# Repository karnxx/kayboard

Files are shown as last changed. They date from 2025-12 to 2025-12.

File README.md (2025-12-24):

# split keyboard - kayboard
https://a360.co/4jg0f7l
basically a keyboard, it can split into 3, which is a left side, a right side and a middle calculator side. so these keyboards can also join together to make 1 big keyboard via rails. 











## hardware
- uses 3  XIAO-nRF52840-SMD, one for each keyboard part. and also uses cherry mx switches.
- https://docs.google.com/spreadsheets/d/1L9tUZh8eFOhgZV8CGI-1AN47H67KgHnQl9KeM_NllnM/edit?usp=sharing

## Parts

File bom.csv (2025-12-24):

item | qty | unit cost | total cost | link | screenshots of cart
Seeed Studio XIAO nRF52840 (SMD) | 3 | 621.6 | 1864.8 | https://www.seeedstudio.com/Seeed-Studio-XIAO-nRF52840-3PCS-p-5921.html
1N5819 THT Diode | 120 | 2.22 | 266.4 | https://robu.in/product/1n5819-1w-diode-pack-of-30/
820 kΩ Resistor | 3 | 2.23 | 6.69 | https://robu.in/product/mccfr0s2j0821a20-multicomp-pro-carbon-film-resistor-820-ohm-500mw-5/?gad_source=1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
2 MΩ Resistor 1/2 W 5pcs pack | 3 | 0.8 | 5 | https://www.electroncomponents.com/2m-resistor-1_2-watt-half-cfr
cherry mx switches | 100 | 160 | 1600 | https://www.banggood.in/100-Pcs-LEOBOG-GrayWood-V3-Switch-Linear-Gray-3Pin-DIY-Gaming-Keyboard-MX-RGB-Hot-Swap-Switch-for-Custom-Mechanical-Keyboard-p-1982818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
 | 10 | 175 | 200 | https://meckeys.com/shop/accessories/keyboard-accessories/key-switches/gateron-g-pro-3-0-switch/
M3 × 4 mm Brass Heat-set Inserts (25 pcs) | 30 | 2.2 | 66 | https://onlyscrews.in/products/m4-x-4mm-brass-threaded-inserts?_pos=3&_sid=18bf98207&_ss=r
M3 × 30 mm SS Screws | 30 | 12.27 | 368 | https://onlyscrews.in/products/m3-x-30mm-phillips-csk-ss-304-screw-dia-3mm-length-30mm
keycaps | 108 | 11.03 | 1600 | https://www.banggood.in/Yogurt-145-Keys-Keycap-Set-Cherry-Profile-PBT-Sublimation-Suitable-for-61-or-68-or-75-or-84-or-87-or-89-or-96-or-98-or-100-or-104-or-1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
battery | 3 | 95 | 285 | https://www.rytronics.in/product/3-7v-300mah-602030-model-lipo-rechargeable-battery/
regulator 3.3v | 3 | 45 | 135 | https://in.element14.com/microchip/mcp1700-1202e-to/ic-ldo-250ma-1-2v-to-92-3/dp/1863922
capacitor 470 | 3 | 4.39 | 13.17 | https://sharvielectronics.com/product/470uf-6-3v-electrolytic-capacitor-85c-6x11mm-samwha/
capacitor 1 | 6 | 28.4 | 170.4
pcb | 1 | 3680 | 5760 (w/shipping)
 |  |  |  | https://evelta.com/1uf-10-50v-x7r-5-5mm-disc-ceramic-capacitor/?utm_source=chatgpt.com
pcb:

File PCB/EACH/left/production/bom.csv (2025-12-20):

Designator | Footprint | Quantity | Value | LCSC Part #
A1, ALT1, B1, C1, CAPS1, CTRL1, D16, E1, ESC1, F1, G1, K1, K2, K3, K4, K5, K6, NN1, NN2, NN3, NN4, NN5, NN6, Q1, R1, S1, SHIFT1, SPACE1, TABS1, TT1, V1, W1, WIN1, X1, X2, X3, Y1, Z1, `1 | SW_Cherry_MX_1.00u_PCB | 39 | SW_Push
BT1 | BatteryHolder_Keystone_1057_1x2032 | 1 | Battery
D1, D10, D11, D12, D13, D14, D15, D17, D18, D19, D2, D20, D21, D22, D23, D24, D25, D26, D27, D28, D29, D3, D30, D31, D32, D33, D34, D35, D36, D37, D38, D39, D4, D40, D5, D6, D7, D8, D9 | D_DO-41_SOD81_P7.62mm_Horizontal | 39 | D
R14, R2 | 0805 | 2 | R
U1 | modified-XIAO-nRF52840-SMD | 1 | XIAO-nRF52840-SMD

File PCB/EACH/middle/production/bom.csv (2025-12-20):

Designator | Footprint | Quantity | Value | LCSC Part #
*1, +1, -2, .2, /1, CTRLT1, CTRLW1, DELETE2, END1, ENTER2, HOME1, INSTERT1, N0\1, N10, N11, N2, N3, N4, N5, N6, N7, N8, N9, NUMLOCK1, PAUSE1, PGDN1, PRTSCRN1, SCRLCK1, VOLDOWN1, VOLUP1 | SW_Cherry_MX_1.00u_PCB | 30 | SW_Push
BT3 | BatteryHolder_Keystone_1057_1x2032 | 1 | Battery
D100, D101, D102, D103, D104, D105, D106, D107, D108, D109, D80, D81, D82, D83, D84, D85, D86, D87, D88, D89, D90, D91, D92, D93, D94, D95, D96, D97, D98, D99 | D_DO-41_SOD81_P7.62mm_Horizontal | 30 | D
R5, R6 | 0805 | 2 | R
U4 | modified-XIAO-nRF52840-SMD | 1 | XIAO-nRF52840-SMD

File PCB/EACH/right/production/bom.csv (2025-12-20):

Designator | Footprint | Quantity | Value | LCSC Part #
'1, ,1, -1, .1, //1, ;1, =1, BACK1, DELETE1, DOWN1, ENTER1, F10\1, F2, F3, F4, F5, H9, I1, J1, K7, KF1, L1, LEFT1, M1, N1, NN10, NN7, NN8, NN9, O1, P1, RIGHT1, U3, UP1, X4, ZSHIFT1, [1, \1, ]1 | SW_Cherry_MX_1.00u_PCB | 39 | SW_Push
BT2 | BatteryHolder_Keystone_1057_1x2032 | 1 | Battery
D41, D42, D43, D44, D45, D46, D47, D48, D49, D50, D51, D52, D53, D54, D55, D56, D57, D58, D59, D60, D61, D62, D63, D64, D65, D66, D67, D68, D69, D70, D71, D72, D73, D74, D75, D76, D77, D78, D79 | D_DO-41_SOD81_P7.62mm_Horizontal | 39 | D
R3, R4 | 0805 | 2 | R
U2 | modified-XIAO-nRF52840-SMD | 1 | XIAO-nRF52840-SMD

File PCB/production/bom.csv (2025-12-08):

Designator | Footprint | Quantity | Value | LCSC Part #
'1, *1, +1, ,1, -1, -2, .1, .2, //1, /1, ;1, =1, A1, ALT1, B1, BACK1, C1, CAPS1, CTRL1, CTRLT1, CTRLW1, D16, DELETE1, DELETE2, DOWN1, E1, END1, ENTER1, ENTER2, ESC1, F1, F10\1, F2, F3, F4, F5, G1, H9, HOME1, I1, INSTERT1, J1, K1, K2, K3, K4, K5, K6, K7, KF1, L1, LEFT1, M1, N0\1, N1, N10, N11, N2, N3, N4, N5, N6, N7, N8, N9, NN1, NN10, NN2, NN3, NN4, NN5, NN6, NN7, NN8, NN9, NUMLOCK1, O1, P1, PAUSE1, PGDN1, PRTSCRN1, Q1, R1, RIGHT1, S1, SCRLCK1, SHIFT1, SPACE1, TABS1, TT1, U3, UP1, V1, VOLDOWN1, VOLUP1, W1, WIN1, X1, X2, X3, X4, Y1, Z1, ZSHIFT1, [1, \1, ]1, `1 | SW_Cherry_MX_1.00u_PCB | 108 | SW_Push
BT1, BT2, BT3 | BatteryHolder_Keystone_1057_1x2032 | 3 | Battery
D1, D10, D100, D101, D102, D103, D104, D105, D106, D107, D108, D109, D11, D12, D13, D14, D15, D17, D18, D19, D2, D20, D21, D22, D23, D24, D25, D26, D27, D28, D29, D3, D30, D31, D32, D33, D34, D35, D36, D37, D38, D39, D4, D40, D41, D42, D43, D44, D45, D46, D47, D48, D49, D5, D50, D51, D52, D53, D54, D55, D56, D57, D58, D59, D6, D60, D61, D62, D63, D64, D65, D66, D67, D68, D69, D7, D70, D71, D72, D73, D74, D75, D76, D77, D78, D79, D8, D80, D81, D82, D83, D84, D85, D86, D87, D88, D89, D9, D90, D91, D92, D93, D94, D95, D96, D97, D98, D99 | D_DO-41_SOD81_P7.62mm_Horizontal | 108 | D
R14, R2, R3, R4, R5, R6 | 0805 | 6 | R
U1, U2, U4 | modified-XIAO-nRF52840-SMD | 3 | XIAO-nRF52840-SMD

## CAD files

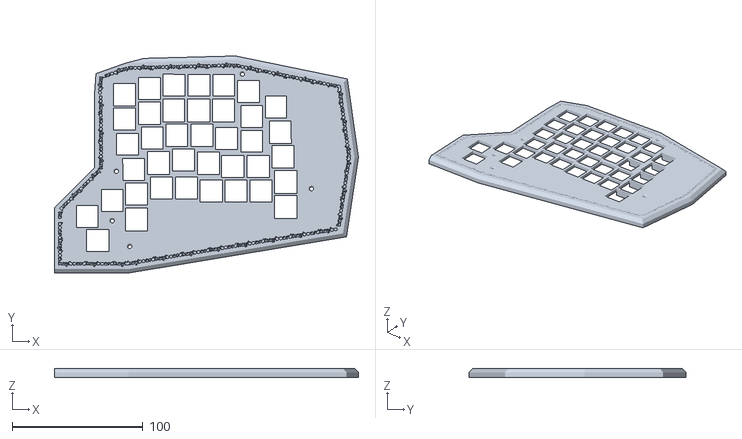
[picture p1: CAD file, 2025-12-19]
CAD/PRINTED/right_top.stl
232.8 x 166.3 x 7.10

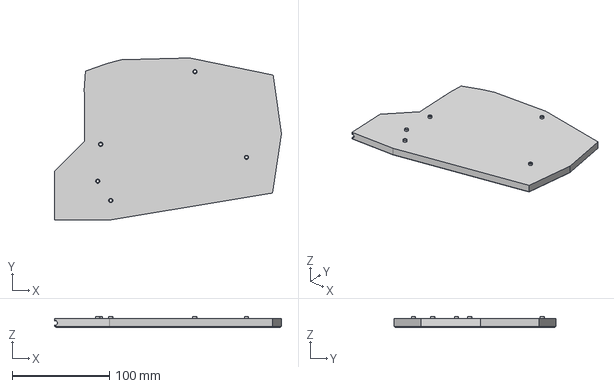
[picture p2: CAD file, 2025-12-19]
CAD/PRINTED/STEP/right_bottom.step
232.8 x 166.3 x 11.0 mm

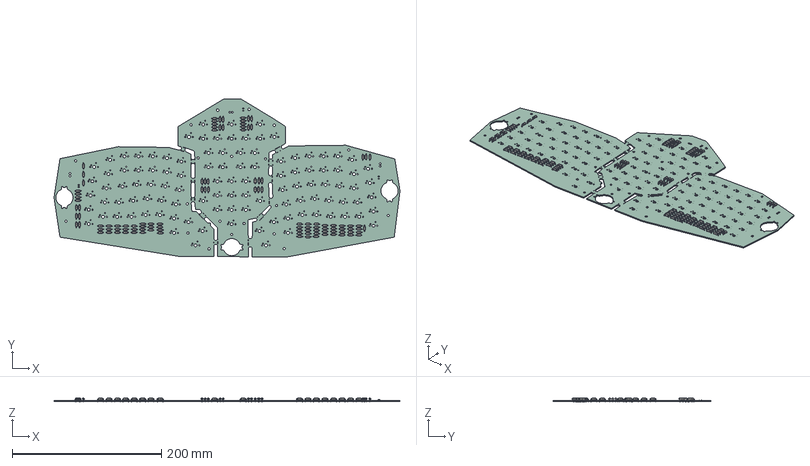
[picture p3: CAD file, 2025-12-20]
PCB/EACH/left/kayboard.step
463.0 x 211.7 x 5.71 mm
D_DO-41_SOD81_P7.62mm_Horizontal x 108
R_0805_2012Metric x 6
kayboard_PCB

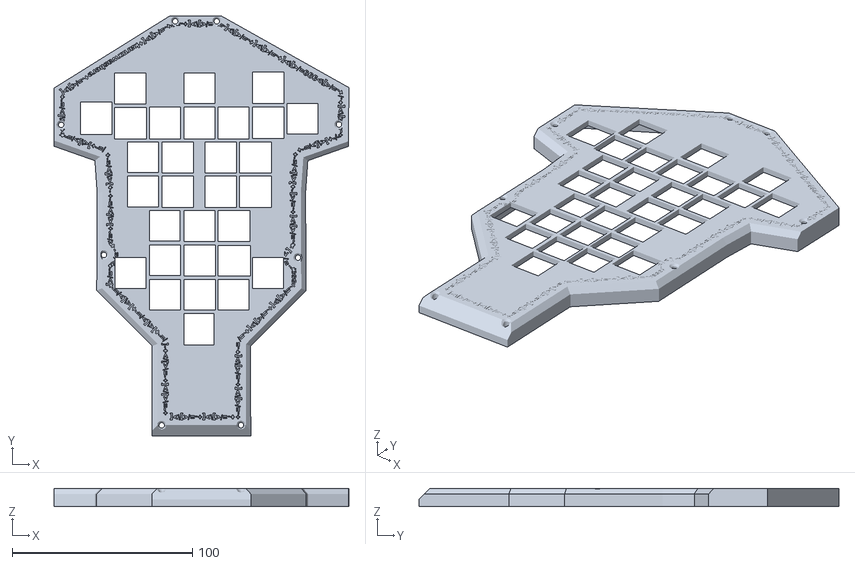
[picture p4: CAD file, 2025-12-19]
CAD/PRINTED/middle_top.stl
163.5 x 233.0 x 10.00

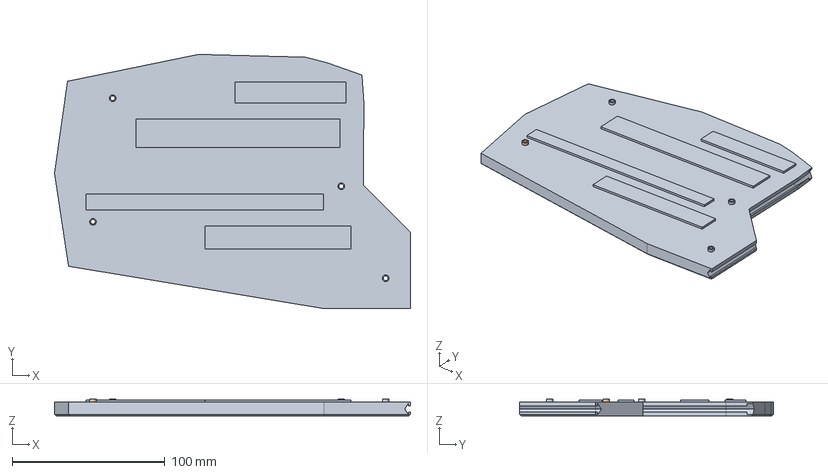
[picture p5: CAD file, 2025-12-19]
CAD/PRINTED/STEP/left_bottom.step
232.8 x 166.3 x 11.0 mm

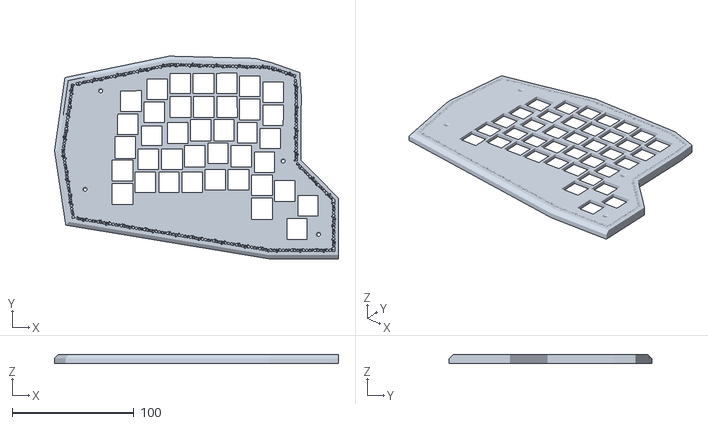
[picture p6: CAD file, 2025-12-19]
CAD/PRINTED/left_top.stl
232.8 x 166.3 x 7.00

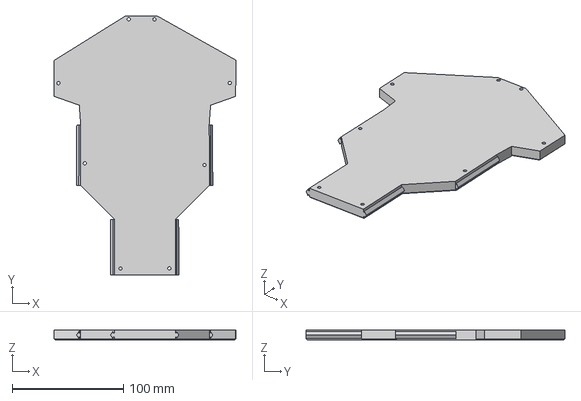
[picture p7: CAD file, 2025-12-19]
CAD/PRINTED/STEP/middle_bottom.step
163.5 x 233.0 x 9.00 mm

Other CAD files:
PCB/kayboard.step
CAD/PRINTED/left_bottom.stl
CAD/PRINTED/middle_bottom.stl
CAD/PRINTED/right_bottom.stl

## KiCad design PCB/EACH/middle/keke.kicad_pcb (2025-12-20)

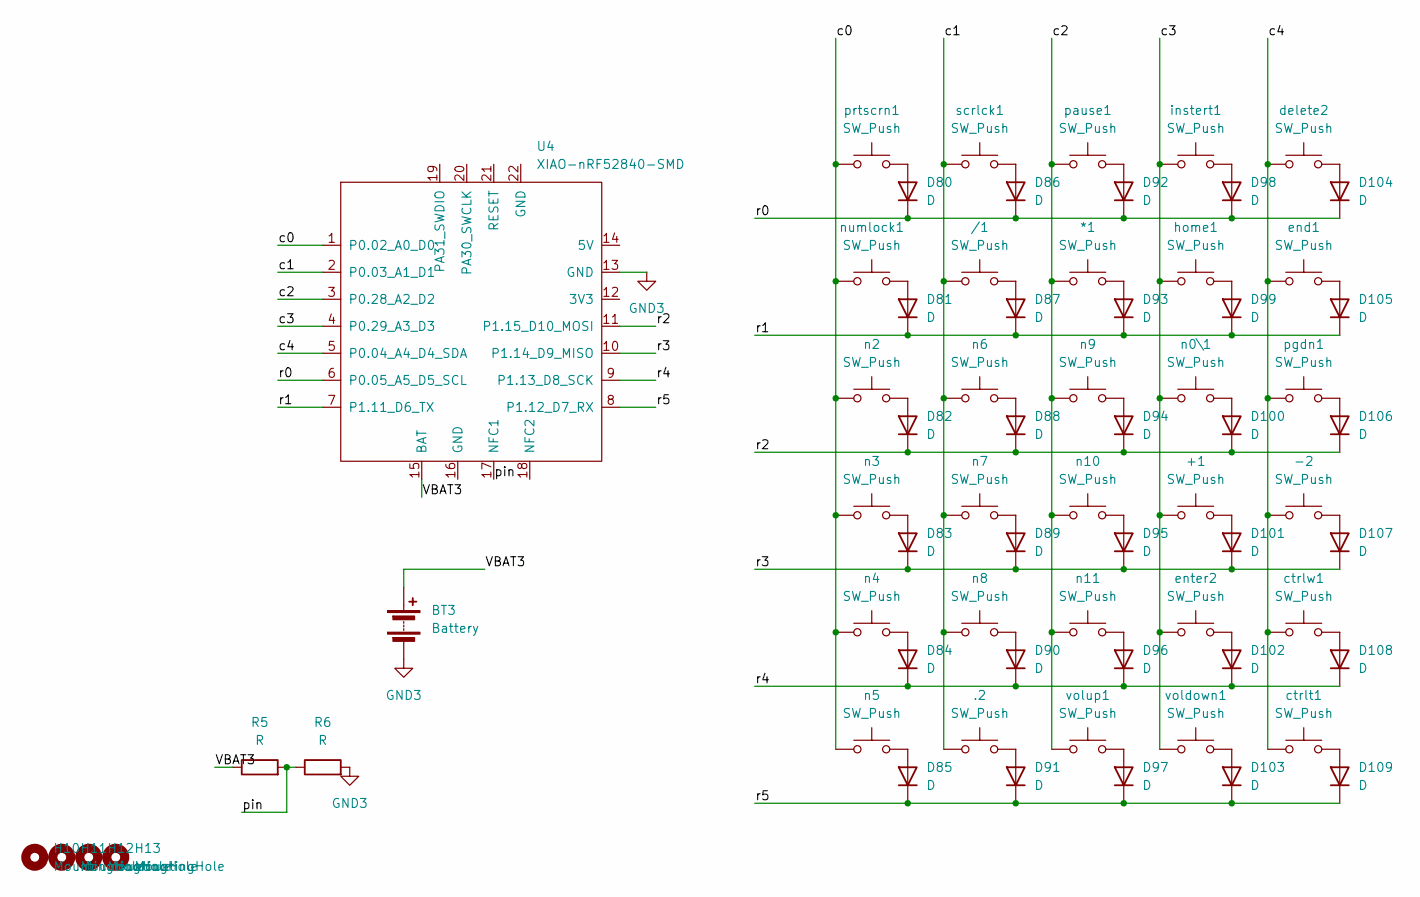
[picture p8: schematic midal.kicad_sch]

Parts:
*1: SW_Push; SW_Cherry_MX_1.00u_PCB
+1: SW_Push; SW_Cherry_MX_1.00u_PCB
-2: SW_Push; SW_Cherry_MX_1.00u_PCB
.2: SW_Push; SW_Cherry_MX_1.00u_PCB
/1: SW_Push; SW_Cherry_MX_1.00u_PCB
BT3: Battery; BatteryHolder_Keystone_1057_1x2032
D80, D81, D82, D83, D84, D85, D86, D87, D88, D89, D90, D91, D92, D93, D94, D95, D96, D97, D98, D99, D100, D101, D102, D103, D104, D105, D106, D107, D108, D109: D; D_DO-41_SOD81_P7.62mm_Horizontal
H10, H11, H12, H13: MountingHole; mouse-bite-5mm-slot
R5, R6: R; R_0805_2012Metric
U4: XIAO-nRF52840-SMD; modified-XIAO-nRF52840-SMD
ctrlt1: SW_Push; SW_Cherry_MX_1.00u_PCB
ctrlw1: SW_Push; SW_Cherry_MX_1.00u_PCB
delete2: SW_Push; SW_Cherry_MX_1.00u_PCB
end1: SW_Push; SW_Cherry_MX_1.00u_PCB
enter2: SW_Push; SW_Cherry_MX_1.00u_PCB
home1: SW_Push; SW_Cherry_MX_1.00u_PCB
instert1: SW_Push; SW_Cherry_MX_1.00u_PCB
n0\1, n2, n3, n4, n5, n6, n7, n8, n9, n10, n11: SW_Push; SW_Cherry_MX_1.00u_PCB
numlock1: SW_Push; SW_Cherry_MX_1.00u_PCB
pause1: SW_Push; SW_Cherry_MX_1.00u_PCB
pgdn1: SW_Push; SW_Cherry_MX_1.00u_PCB
prtscrn1: SW_Push; SW_Cherry_MX_1.00u_PCB
scrlck1: SW_Push; SW_Cherry_MX_1.00u_PCB
voldown1: SW_Push; SW_Cherry_MX_1.00u_PCB
volup1: SW_Push; SW_Cherry_MX_1.00u_PCB

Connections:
/middle/VBAT3: BT3.1 (+), R5.1, U4.15 (BAT)
/middle/c0: U4.1 (P0.02_A0_D0), n2.1, n3.1, n4.1, n5.1, numlock1.1, prtscrn1.1
/middle/c1: .2.1, /1.1, U4.2 (P0.03_A1_D1), n6.1, n7.1, n8.1, scrlck1.1
/middle/c2: *1.1, U4.3 (P0.28_A2_D2), n9.1, n10.1, n11.1, pause1.1, volup1.1
/middle/c3: +1.1, U4.4 (P0.29_A3_D3), enter2.1, home1.1, instert1.1, n0\1.1, voldown1.1
/middle/c4: -2.1, U4.5 (P0.04_A4_D4_SDA), ctrlt1.1, ctrlw1.1, delete2.1, end1.1, pgdn1.1
/middle/pin: R5.2, R6.1, U4.17 (NFC1)
/middle/r0: D80.1 (K), D86.1 (K), D92.1 (K), D98.1 (K), D104.1 (K), U4.6 (P0.05_A5_D5_SCL)
/middle/r1: D81.1 (K), D87.1 (K), D93.1 (K), D99.1 (K), D105.1 (K), U4.7 (P1.11_D6_TX)
/middle/r2: D82.1 (K), D88.1 (K), D94.1 (K), D100.1 (K), D106.1 (K), U4.11 (P1.15_D10_MOSI)
/middle/r3: D83.1 (K), D89.1 (K), D95.1 (K), D101.1 (K), D107.1 (K), U4.10 (P1.14_D9_MISO)
/middle/r4: D84.1 (K), D90.1 (K), D96.1 (K), D102.1 (K), D108.1 (K), U4.9 (P1.13_D8_SCK)
/middle/r5: D85.1 (K), D91.1 (K), D97.1 (K), D103.1 (K), D109.1 (K), U4.8 (P1.12_D7_RX)
GND3: BT3.2 (-), R6.2, U4.13 (GND)
unnamed: D80.2 (A), prtscrn1.2
unnamed: D81.2 (A), numlock1.2
unnamed: D82.2 (A), n2.2
unnamed: D83.2 (A), n3.2
unnamed: D84.2 (A), n4.2
unnamed: D85.2 (A), n5.2
unnamed: D86.2 (A), scrlck1.2
unnamed: /1.2, D87.2 (A)
unnamed: D88.2 (A), n6.2
unnamed: D89.2 (A), n7.2
unnamed: D90.2 (A), n8.2
unnamed: .2.2, D91.2 (A)
unnamed: D92.2 (A), pause1.2
unnamed: *1.2, D93.2 (A)
unnamed: D94.2 (A), n9.2
unnamed: D95.2 (A), n10.2
unnamed: D96.2 (A), n11.2
unnamed: D97.2 (A), volup1.2
unnamed: D98.2 (A), instert1.2
unnamed: D99.2 (A), home1.2
unnamed: D100.2 (A), n0\1.2
unnamed: +1.2, D101.2 (A)
unnamed: D102.2 (A), enter2.2
unnamed: D103.2 (A), voldown1.2
unnamed: D104.2 (A), delete2.2
unnamed: D105.2 (A), end1.2
unnamed: D106.2 (A), pgdn1.2
unnamed: -2.2, D107.2 (A)
unnamed: D108.2 (A), ctrlw1.2
unnamed: D109.2 (A), ctrlt1.2

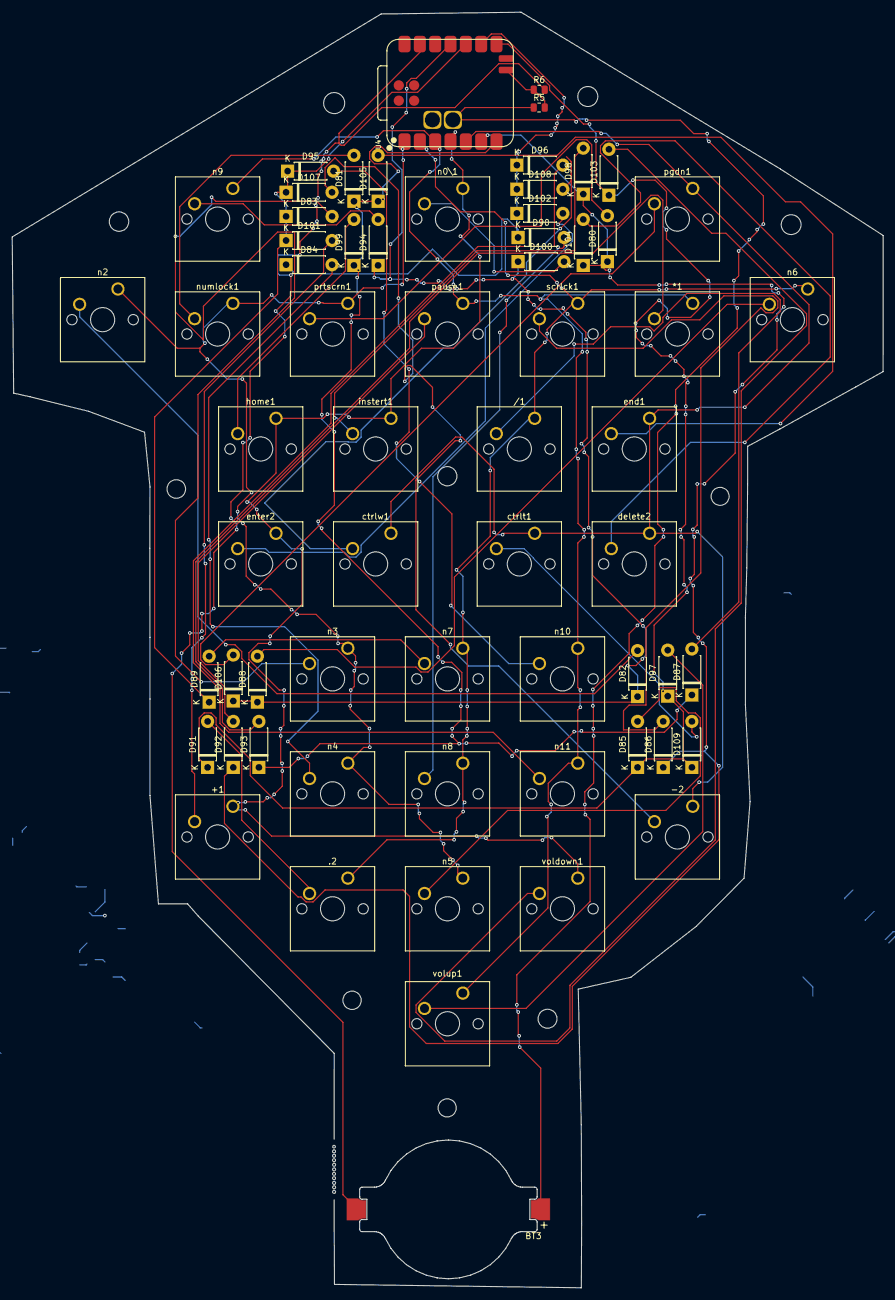
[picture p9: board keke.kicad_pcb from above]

Board: 2 copper layers, 144.3 x 211.4 mm, 64 parts (0 on the bottom side), 44 nets.

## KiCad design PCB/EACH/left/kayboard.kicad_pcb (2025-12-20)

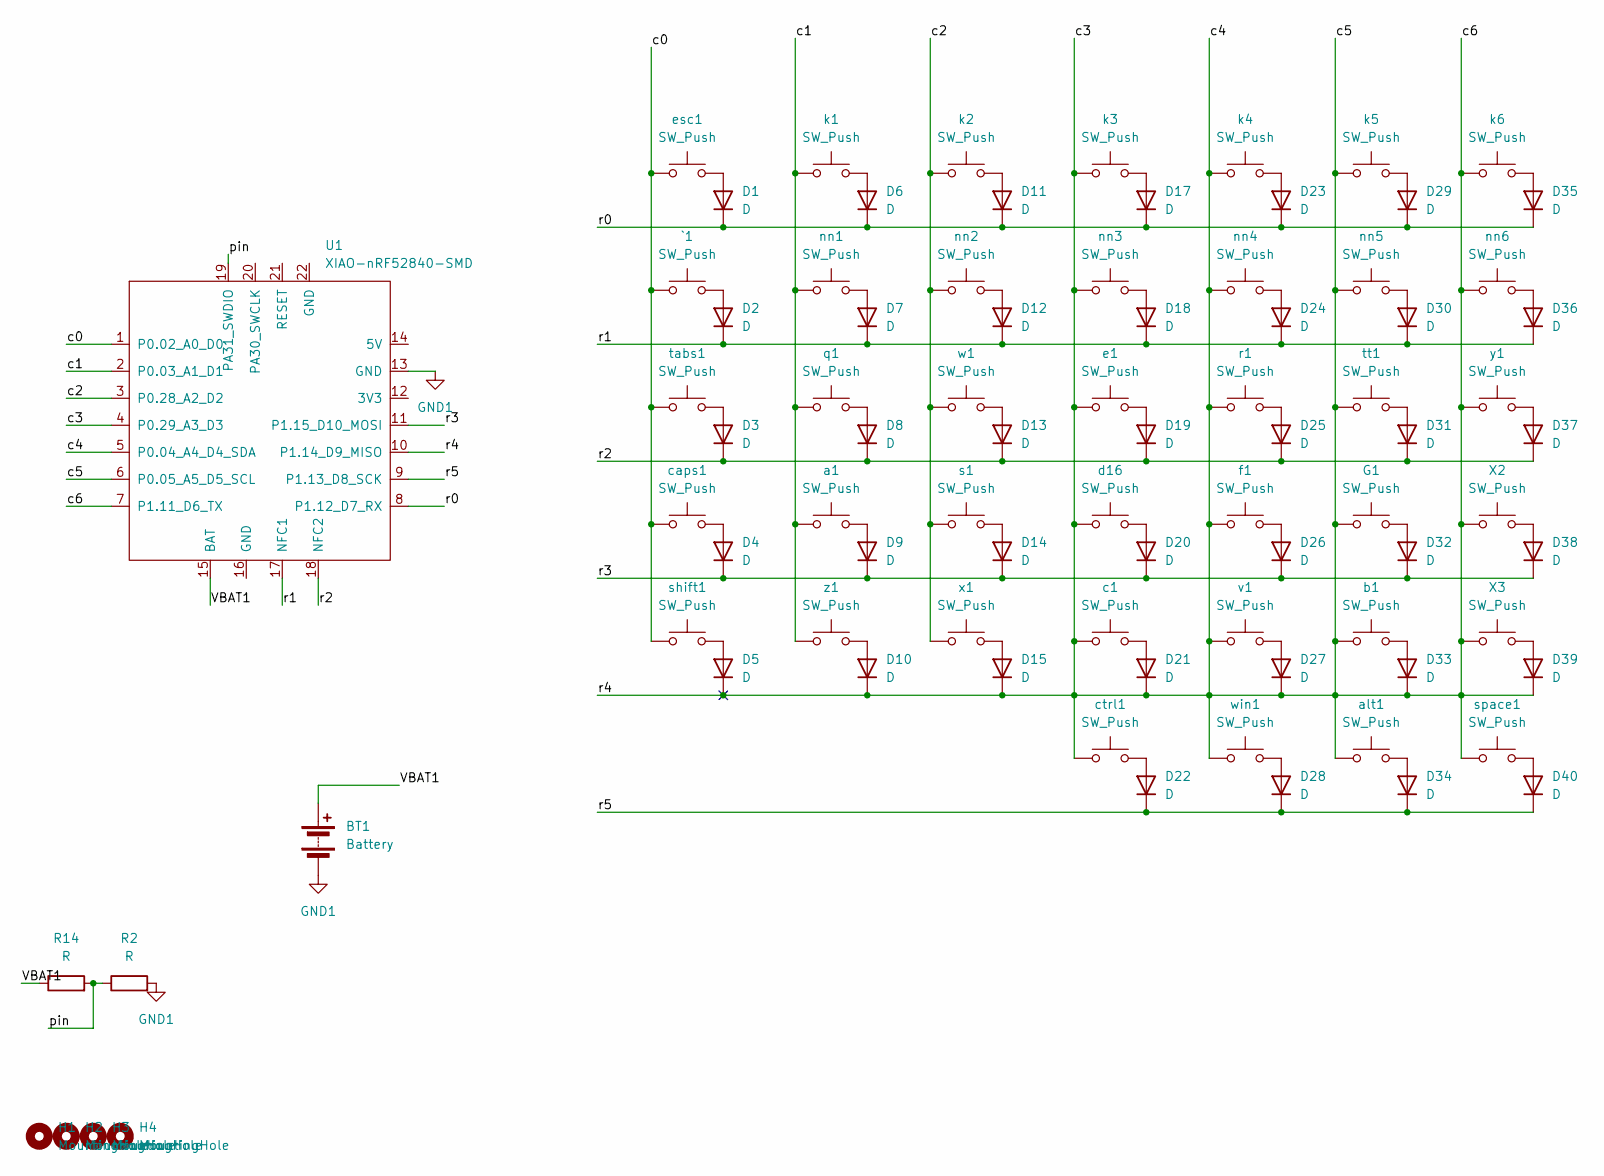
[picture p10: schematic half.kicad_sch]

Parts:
BT1: Battery; BatteryHolder_Keystone_1057_1x2032
D1, D2, D3, D4, D5, D6, D7, D8, D9, D10, D11, D12, D13, D14, D15, D17, D18, D19, D20, D21, D22, D23, D24, D25, D26, D27, D28, D29, D30, D31, D32, D33, D34, D35, D36, D37, D38, D39, D40: D; D_DO-41_SOD81_P7.62mm_Horizontal
G1: SW_Push; SW_Cherry_MX_1.00u_PCB
H1, H2, H3, H4: MountingHole; mouse-bite-5mm-slot
R2, R14: R; R_0805_2012Metric
U1: XIAO-nRF52840-SMD; modified-XIAO-nRF52840-SMD
X2, X3: SW_Push; SW_Cherry_MX_1.00u_PCB
`1: SW_Push; SW_Cherry_MX_1.00u_PCB
a1: SW_Push; SW_Cherry_MX_1.00u_PCB
alt1: SW_Push; SW_Cherry_MX_1.00u_PCB
b1: SW_Push; SW_Cherry_MX_1.00u_PCB
c1: SW_Push; SW_Cherry_MX_1.00u_PCB
caps1: SW_Push; SW_Cherry_MX_1.00u_PCB
ctrl1: SW_Push; SW_Cherry_MX_1.00u_PCB
d16: SW_Push; SW_Cherry_MX_1.00u_PCB
e1: SW_Push; SW_Cherry_MX_1.00u_PCB
esc1: SW_Push; SW_Cherry_MX_1.00u_PCB
f1: SW_Push; SW_Cherry_MX_1.00u_PCB
k1, k2, k3, k4, k5, k6: SW_Push; SW_Cherry_MX_1.00u_PCB
nn1, nn2, nn3, nn4, nn5, nn6: SW_Push; SW_Cherry_MX_1.00u_PCB
q1: SW_Push; SW_Cherry_MX_1.00u_PCB
r1: SW_Push; SW_Cherry_MX_1.00u_PCB
s1: SW_Push; SW_Cherry_MX_1.00u_PCB
shift1: SW_Push; SW_Cherry_MX_1.00u_PCB
space1: SW_Push; SW_Cherry_MX_1.00u_PCB
tabs1: SW_Push; SW_Cherry_MX_1.00u_PCB
tt1: SW_Push; SW_Cherry_MX_1.00u_PCB
v1: SW_Push; SW_Cherry_MX_1.00u_PCB
w1: SW_Push; SW_Cherry_MX_1.00u_PCB
win1: SW_Push; SW_Cherry_MX_1.00u_PCB
x1: SW_Push; SW_Cherry_MX_1.00u_PCB
y1: SW_Push; SW_Cherry_MX_1.00u_PCB
z1: SW_Push; SW_Cherry_MX_1.00u_PCB

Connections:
/left/VBAT1: BT1.1 (+), R14.1, U1.15 (BAT)
/left/c0: U1.1 (P0.02_A0_D0), `1.1, caps1.1, esc1.1, shift1.1, tabs1.1
/left/c1: U1.2 (P0.03_A1_D1), a1.1, k1.1, nn1.1, q1.1, z1.1
/left/c2: U1.3 (P0.28_A2_D2), k2.1, nn2.1, s1.1, w1.1, x1.1
/left/c3: D5.1 (K), D10.1 (K), D15.1 (K), D21.1 (K), D27.1 (K), D33.1 (K), D39.1 (K), G1.1, U1.4 (P0.29_A3_D3), U1.5 (P0.04_A4_D4_SDA), U1.6 (P0.05_A5_D5_SCL), U1.7 (P1.11_D6_TX), U1.10 (P1.14_D9_MISO), X2.1, X3.1, alt1.1, b1.1, c1.1, ctrl1.1, d16.1, e1.1, f1.1, k3.1, k4.1, k5.1, k6.1, nn3.1, nn4.1, nn5.1, nn6.1, r1.1, space1.1, tt1.1, v1.1, win1.1, y1.1
/left/pin: R2.1, R14.2, U1.19 (PA31_SWDIO)
/left/r0: D1.1 (K), D6.1 (K), D11.1 (K), D17.1 (K), D23.1 (K), D29.1 (K), D35.1 (K), U1.8 (P1.12_D7_RX)
/left/r1: D2.1 (K), D7.1 (K), D12.1 (K), D18.1 (K), D24.1 (K), D30.1 (K), D36.1 (K), U1.17 (NFC1)
/left/r2: D3.1 (K), D8.1 (K), D13.1 (K), D19.1 (K), D25.1 (K), D31.1 (K), D37.1 (K), U1.18 (NFC2)
/left/r3: D4.1 (K), D9.1 (K), D14.1 (K), D20.1 (K), D26.1 (K), D32.1 (K), D38.1 (K), U1.11 (P1.15_D10_MOSI)
/left/r5: D22.1 (K), D28.1 (K), D34.1 (K), D40.1 (K), U1.9 (P1.13_D8_SCK)
GND1: BT1.2 (-), R2.2, U1.13 (GND)
unnamed: D1.2 (A), esc1.2
unnamed: D2.2 (A), `1.2
unnamed: D3.2 (A), tabs1.2
unnamed: D4.2 (A), caps1.2
unnamed: D5.2 (A), shift1.2
unnamed: D6.2 (A), k1.2
unnamed: D7.2 (A), nn1.2
unnamed: D8.2 (A), q1.2
unnamed: D9.2 (A), a1.2
unnamed: D10.2 (A), z1.2
unnamed: D11.2 (A), k2.2
unnamed: D12.2 (A), nn2.2
unnamed: D13.2 (A), w1.2
unnamed: D14.2 (A), s1.2
unnamed: D15.2 (A), x1.2
unnamed: D17.2 (A), k3.2
unnamed: D18.2 (A), nn3.2
unnamed: D19.2 (A), e1.2
unnamed: D20.2 (A), d16.2
unnamed: D21.2 (A), c1.2
unnamed: D22.2 (A), ctrl1.2
unnamed: D23.2 (A), k4.2
unnamed: D24.2 (A), nn4.2
unnamed: D25.2 (A), r1.2
unnamed: D26.2 (A), f1.2
unnamed: D27.2 (A), v1.2
unnamed: D28.2 (A), win1.2
unnamed: D29.2 (A), k5.2
unnamed: D30.2 (A), nn5.2
unnamed: D31.2 (A), tt1.2
unnamed: D32.2 (A), G1.2
unnamed: D33.2 (A), b1.2
unnamed: D34.2 (A), alt1.2
unnamed: D35.2 (A), k6.2
unnamed: D36.2 (A), nn6.2
unnamed: D37.2 (A), y1.2
unnamed: D38.2 (A), X2.2
unnamed: D39.2 (A), X3.2
unnamed: D40.2 (A), space1.2

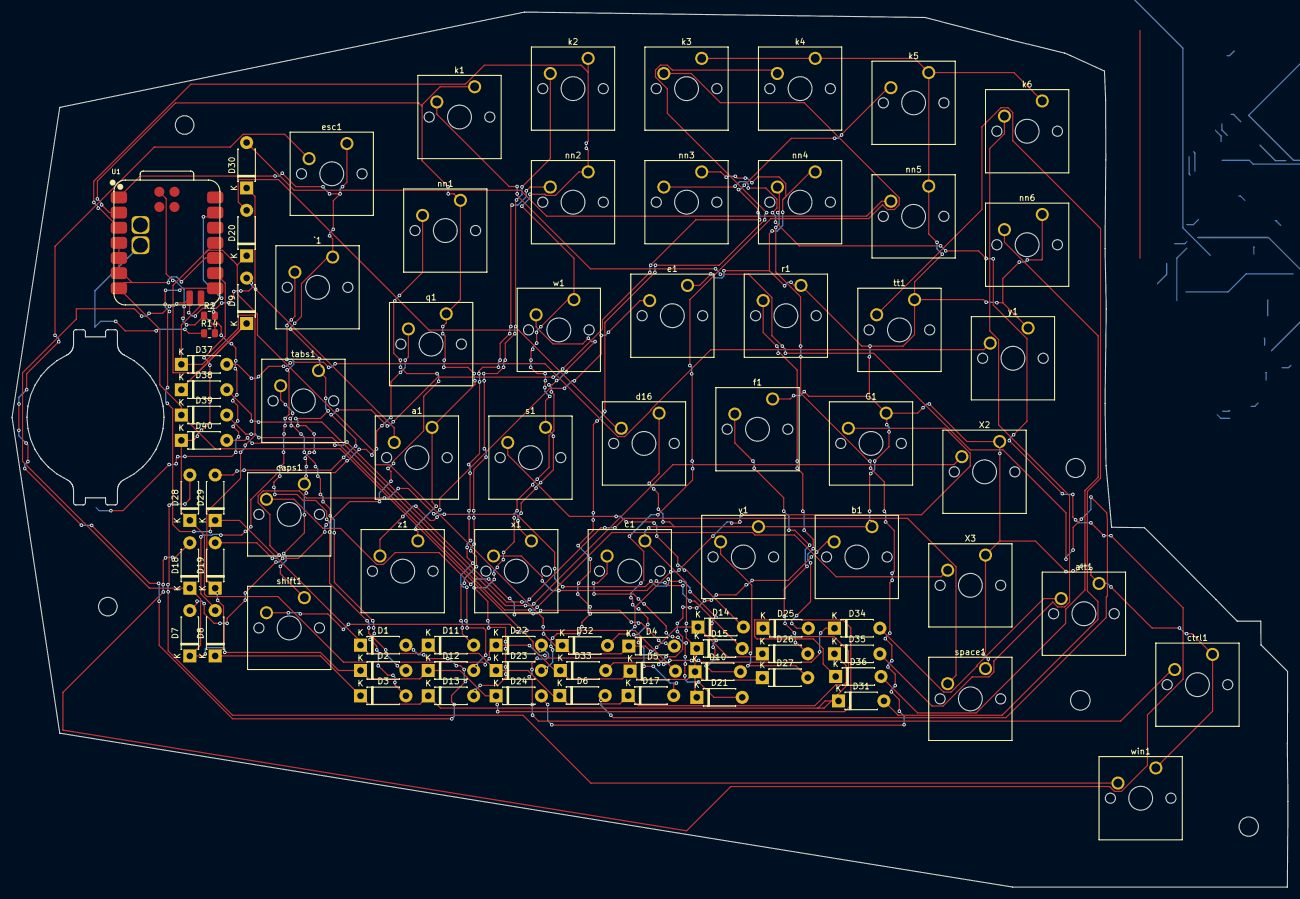
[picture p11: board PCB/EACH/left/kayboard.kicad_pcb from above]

Board: 2 copper layers, 214.1 x 146.8 mm, 82 parts (1 on the bottom side), 51 nets.

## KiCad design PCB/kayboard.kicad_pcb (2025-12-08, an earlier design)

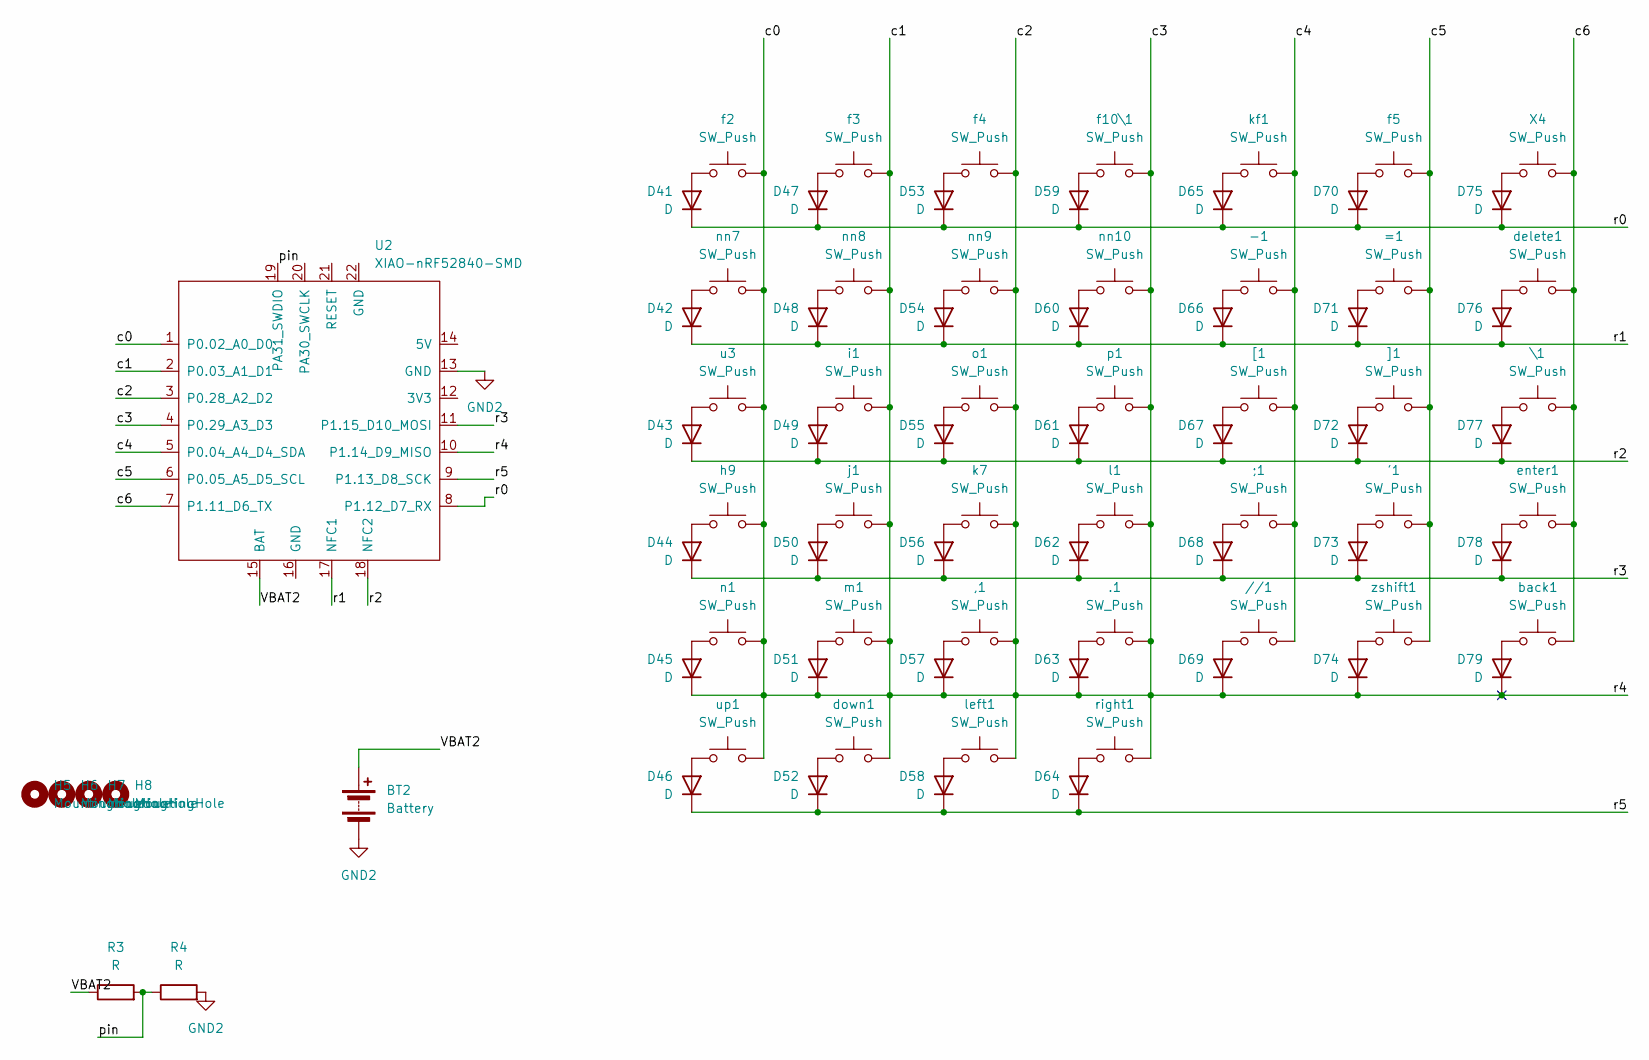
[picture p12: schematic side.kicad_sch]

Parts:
'1: SW_Push; SW_Cherry_MX_1.00u_PCB
,1: SW_Push; SW_Cherry_MX_1.00u_PCB
-1: SW_Push; SW_Cherry_MX_1.00u_PCB
.1: SW_Push; SW_Cherry_MX_1.00u_PCB
//1: SW_Push; SW_Cherry_MX_1.00u_PCB
;1: SW_Push; SW_Cherry_MX_1.00u_PCB
=1: SW_Push; SW_Cherry_MX_1.00u_PCB
BT2: Battery; BatteryHolder_Keystone_1057_1x2032
D41, D42, D43, D44, D45, D46, D47, D48, D49, D50, D51, D52, D53, D54, D55, D56, D57, D58, D59, D60, D61, D62, D63, D64, D65, D66, D67, D68, D69, D70, D71, D72, D73, D74, D75, D76, D77, D78, D79: D; D_DO-41_SOD81_P7.62mm_Horizontal
H5, H6, H7, H8: MountingHole; mouse-bite-5mm-slot
R3, R4: R; R_0805_2012Metric
U2: XIAO-nRF52840-SMD; modified-XIAO-nRF52840-SMD
X4: SW_Push; SW_Cherry_MX_1.00u_PCB
[1: SW_Push; SW_Cherry_MX_1.00u_PCB
\1: SW_Push; SW_Cherry_MX_1.00u_PCB
]1: SW_Push; SW_Cherry_MX_1.00u_PCB
back1: SW_Push; SW_Cherry_MX_1.00u_PCB
delete1: SW_Push; SW_Cherry_MX_1.00u_PCB
down1: SW_Push; SW_Cherry_MX_1.00u_PCB
enter1: SW_Push; SW_Cherry_MX_1.00u_PCB
f2, f3, f4, f5, f10\1: SW_Push; SW_Cherry_MX_1.00u_PCB
h9: SW_Push; SW_Cherry_MX_1.00u_PCB
i1: SW_Push; SW_Cherry_MX_1.00u_PCB
j1: SW_Push; SW_Cherry_MX_1.00u_PCB
k7: SW_Push; SW_Cherry_MX_1.00u_PCB
kf1: SW_Push; SW_Cherry_MX_1.00u_PCB
l1: SW_Push; SW_Cherry_MX_1.00u_PCB
left1: SW_Push; SW_Cherry_MX_1.00u_PCB
m1: SW_Push; SW_Cherry_MX_1.00u_PCB
n1: SW_Push; SW_Cherry_MX_1.00u_PCB
nn7, nn8, nn9, nn10: SW_Push; SW_Cherry_MX_1.00u_PCB
o1: SW_Push; SW_Cherry_MX_1.00u_PCB
p1: SW_Push; SW_Cherry_MX_1.00u_PCB
right1: SW_Push; SW_Cherry_MX_1.00u_PCB
u3: SW_Push; SW_Cherry_MX_1.00u_PCB
up1: SW_Push; SW_Cherry_MX_1.00u_PCB
zshift1: SW_Push; SW_Cherry_MX_1.00u_PCB

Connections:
/right/VBAT2: BT2.1 (+), R3.1, U2.15 (BAT)
/right/c0: ,1.1, .1.1, D45.1 (K), D51.1 (K), D57.1 (K), D63.1 (K), D69.1 (K), D74.1 (K), D79.1 (K), U2.1 (P0.02_A0_D0), U2.2 (P0.03_A1_D1), U2.3 (P0.28_A2_D2), U2.4 (P0.29_A3_D3), U2.10 (P1.14_D9_MISO), down1.1, f2.1, f3.1, f4.1, f10\1.1, h9.1, i1.1, j1.1, k7.1, l1.1, left1.1, m1.1, n1.1, nn7.1, nn8.1, nn9.1, nn10.1, o1.1, p1.1, right1.1, u3.1, up1.1
/right/c4: -1.1, //1.1, ;1.1, U2.5 (P0.04_A4_D4_SDA), [1.1, kf1.1
/right/c5: '1.1, =1.1, U2.6 (P0.05_A5_D5_SCL), ]1.1, f5.1, zshift1.1
/right/c6: U2.7 (P1.11_D6_TX), X4.1, \1.1, back1.1, delete1.1, enter1.1
/right/pin: R3.2, R4.1, U2.19 (PA31_SWDIO)
/right/r0: D41.1 (K), D47.1 (K), D53.1 (K), D59.1 (K), D65.1 (K), D70.1 (K), D75.1 (K), U2.8 (P1.12_D7_RX)
/right/r1: D42.1 (K), D48.1 (K), D54.1 (K), D60.1 (K), D66.1 (K), D71.1 (K), D76.1 (K), U2.17 (NFC1)
/right/r2: D43.1 (K), D49.1 (K), D55.1 (K), D61.1 (K), D67.1 (K), D72.1 (K), D77.1 (K), U2.18 (NFC2)
/right/r3: D44.1 (K), D50.1 (K), D56.1 (K), D62.1 (K), D68.1 (K), D73.1 (K), D78.1 (K), U2.11 (P1.15_D10_MOSI)
/right/r5: D46.1 (K), D52.1 (K), D58.1 (K), D64.1 (K), U2.9 (P1.13_D8_SCK)
GND2: BT2.2 (-), R4.2, U2.13 (GND)
unnamed: D41.2 (A), f2.2
unnamed: D42.2 (A), nn7.2
unnamed: D43.2 (A), u3.2
unnamed: D44.2 (A), h9.2
unnamed: D45.2 (A), n1.2
unnamed: D46.2 (A), up1.2
unnamed: D47.2 (A), f3.2
unnamed: D48.2 (A), nn8.2
unnamed: D49.2 (A), i1.2
unnamed: D50.2 (A), j1.2
unnamed: D51.2 (A), m1.2
unnamed: D52.2 (A), down1.2
unnamed: D53.2 (A), f4.2
unnamed: D54.2 (A), nn9.2
unnamed: D55.2 (A), o1.2
unnamed: D56.2 (A), k7.2
unnamed: ,1.2, D57.2 (A)
unnamed: D58.2 (A), left1.2
unnamed: D59.2 (A), f10\1.2
unnamed: D60.2 (A), nn10.2
unnamed: D61.2 (A), p1.2
unnamed: D62.2 (A), l1.2
unnamed: .1.2, D63.2 (A)
unnamed: D64.2 (A), right1.2
unnamed: D65.2 (A), kf1.2
unnamed: -1.2, D66.2 (A)
unnamed: D67.2 (A), [1.2
unnamed: ;1.2, D68.2 (A)
unnamed: //1.2, D69.2 (A)
unnamed: D70.2 (A), f5.2
unnamed: =1.2, D71.2 (A)
unnamed: D72.2 (A), ]1.2
unnamed: '1.2, D73.2 (A)
unnamed: D74.2 (A), zshift1.2
unnamed: D75.2 (A), X4.2
unnamed: D76.2 (A), delete1.2
unnamed: D77.2 (A), \1.2
unnamed: D78.2 (A), enter1.2
unnamed: D79.2 (A), back1.2


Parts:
BT1: Battery; BatteryHolder_Keystone_1057_1x2032
D1, D2, D3, D4, D5, D6, D7, D8, D9, D10, D11, D12, D13, D14, D15, D17, D18, D19, D20, D21, D22, D23, D24, D25, D26, D27, D28, D29, D30, D31, D32, D33, D34, D35, D36, D37, D38, D39, D40: D; D_DO-41_SOD81_P7.62mm_Horizontal
G1: SW_Push; SW_Cherry_MX_1.00u_PCB
H1, H2, H3, H4: MountingHole; mouse-bite-5mm-slot
R2, R14: R; R_0805_2012Metric
U1: XIAO-nRF52840-SMD; modified-XIAO-nRF52840-SMD
X2, X3: SW_Push; SW_Cherry_MX_1.00u_PCB
`1: SW_Push; SW_Cherry_MX_1.00u_PCB
a1: SW_Push; SW_Cherry_MX_1.00u_PCB
alt1: SW_Push; SW_Cherry_MX_1.00u_PCB
b1: SW_Push; SW_Cherry_MX_1.00u_PCB
c1: SW_Push; SW_Cherry_MX_1.00u_PCB
caps1: SW_Push; SW_Cherry_MX_1.00u_PCB
ctrl1: SW_Push; SW_Cherry_MX_1.00u_PCB
d16: SW_Push; SW_Cherry_MX_1.00u_PCB
e1: SW_Push; SW_Cherry_MX_1.00u_PCB
esc1: SW_Push; SW_Cherry_MX_1.00u_PCB
f1: SW_Push; SW_Cherry_MX_1.00u_PCB
k1, k2, k3, k4, k5, k6: SW_Push; SW_Cherry_MX_1.00u_PCB
nn1, nn2, nn3, nn4, nn5, nn6: SW_Push; SW_Cherry_MX_1.00u_PCB
q1: SW_Push; SW_Cherry_MX_1.00u_PCB
r1: SW_Push; SW_Cherry_MX_1.00u_PCB
s1: SW_Push; SW_Cherry_MX_1.00u_PCB
shift1: SW_Push; SW_Cherry_MX_1.00u_PCB
space1: SW_Push; SW_Cherry_MX_1.00u_PCB
tabs1: SW_Push; SW_Cherry_MX_1.00u_PCB
tt1: SW_Push; SW_Cherry_MX_1.00u_PCB
v1: SW_Push; SW_Cherry_MX_1.00u_PCB
w1: SW_Push; SW_Cherry_MX_1.00u_PCB
win1: SW_Push; SW_Cherry_MX_1.00u_PCB
x1: SW_Push; SW_Cherry_MX_1.00u_PCB
y1: SW_Push; SW_Cherry_MX_1.00u_PCB
z1: SW_Push; SW_Cherry_MX_1.00u_PCB

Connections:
/left/VBAT1: BT1.1 (+), R14.1, U1.15 (BAT)
/left/c0: U1.1 (P0.02_A0_D0), `1.1, caps1.1, esc1.1, shift1.1, tabs1.1
/left/c1: U1.2 (P0.03_A1_D1), a1.1, k1.1, nn1.1, q1.1, z1.1
/left/c2: U1.3 (P0.28_A2_D2), k2.1, nn2.1, s1.1, w1.1, x1.1
/left/c3: D5.1 (K), D10.1 (K), D15.1 (K), D21.1 (K), D27.1 (K), D33.1 (K), D39.1 (K), G1.1, U1.4 (P0.29_A3_D3), U1.5 (P0.04_A4_D4_SDA), U1.6 (P0.05_A5_D5_SCL), U1.7 (P1.11_D6_TX), U1.10 (P1.14_D9_MISO), X2.1, X3.1, alt1.1, b1.1, c1.1, ctrl1.1, d16.1, e1.1, f1.1, k3.1, k4.1, k5.1, k6.1, nn3.1, nn4.1, nn5.1, nn6.1, r1.1, space1.1, tt1.1, v1.1, win1.1, y1.1
/left/pin: R2.1, R14.2, U1.19 (PA31_SWDIO)
/left/r0: D1.1 (K), D6.1 (K), D11.1 (K), D17.1 (K), D23.1 (K), D29.1 (K), D35.1 (K), U1.8 (P1.12_D7_RX)
/left/r1: D2.1 (K), D7.1 (K), D12.1 (K), D18.1 (K), D24.1 (K), D30.1 (K), D36.1 (K), U1.17 (NFC1)
/left/r2: D3.1 (K), D8.1 (K), D13.1 (K), D19.1 (K), D25.1 (K), D31.1 (K), D37.1 (K), U1.18 (NFC2)
/left/r3: D4.1 (K), D9.1 (K), D14.1 (K), D20.1 (K), D26.1 (K), D32.1 (K), D38.1 (K), U1.11 (P1.15_D10_MOSI)
/left/r5: D22.1 (K), D28.1 (K), D34.1 (K), D40.1 (K), U1.9 (P1.13_D8_SCK)
GND1: BT1.2 (-), R2.2, U1.13 (GND)
unnamed: D1.2 (A), esc1.2
unnamed: D2.2 (A), `1.2
unnamed: D3.2 (A), tabs1.2
unnamed: D4.2 (A), caps1.2
unnamed: D5.2 (A), shift1.2
unnamed: D6.2 (A), k1.2
unnamed: D7.2 (A), nn1.2
unnamed: D8.2 (A), q1.2
unnamed: D9.2 (A), a1.2
unnamed: D10.2 (A), z1.2
unnamed: D11.2 (A), k2.2
unnamed: D12.2 (A), nn2.2
unnamed: D13.2 (A), w1.2
unnamed: D14.2 (A), s1.2
unnamed: D15.2 (A), x1.2
unnamed: D17.2 (A), k3.2
unnamed: D18.2 (A), nn3.2
unnamed: D19.2 (A), e1.2
unnamed: D20.2 (A), d16.2
unnamed: D21.2 (A), c1.2
unnamed: D22.2 (A), ctrl1.2
unnamed: D23.2 (A), k4.2
unnamed: D24.2 (A), nn4.2
unnamed: D25.2 (A), r1.2
unnamed: D26.2 (A), f1.2
unnamed: D27.2 (A), v1.2
unnamed: D28.2 (A), win1.2
unnamed: D29.2 (A), k5.2
unnamed: D30.2 (A), nn5.2
unnamed: D31.2 (A), tt1.2
unnamed: D32.2 (A), G1.2
unnamed: D33.2 (A), b1.2
unnamed: D34.2 (A), alt1.2
unnamed: D35.2 (A), k6.2
unnamed: D36.2 (A), nn6.2
unnamed: D37.2 (A), y1.2
unnamed: D38.2 (A), X2.2
unnamed: D39.2 (A), X3.2
unnamed: D40.2 (A), space1.2


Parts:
*1: SW_Push; SW_Cherry_MX_1.00u_PCB
+1: SW_Push; SW_Cherry_MX_1.00u_PCB
-2: SW_Push; SW_Cherry_MX_1.00u_PCB
.2: SW_Push; SW_Cherry_MX_1.00u_PCB
/1: SW_Push; SW_Cherry_MX_1.00u_PCB
BT3: Battery; BatteryHolder_Keystone_1057_1x2032
D80, D81, D82, D83, D84, D85, D86, D87, D88, D89, D90, D91, D92, D93, D94, D95, D96, D97, D98, D99, D100, D101, D102, D103, D104, D105, D106, D107, D108, D109: D; D_DO-41_SOD81_P7.62mm_Horizontal
H10, H11, H12, H13: MountingHole; mouse-bite-5mm-slot
R5, R6: R; R_0805_2012Metric
U4: XIAO-nRF52840-SMD; modified-XIAO-nRF52840-SMD
ctrlt1: SW_Push; SW_Cherry_MX_1.00u_PCB
ctrlw1: SW_Push; SW_Cherry_MX_1.00u_PCB
delete2: SW_Push; SW_Cherry_MX_1.00u_PCB
end1: SW_Push; SW_Cherry_MX_1.00u_PCB
enter2: SW_Push; SW_Cherry_MX_1.00u_PCB
home1: SW_Push; SW_Cherry_MX_1.00u_PCB
instert1: SW_Push; SW_Cherry_MX_1.00u_PCB
n0\1, n2, n3, n4, n5, n6, n7, n8, n9, n10, n11: SW_Push; SW_Cherry_MX_1.00u_PCB
numlock1: SW_Push; SW_Cherry_MX_1.00u_PCB
pause1: SW_Push; SW_Cherry_MX_1.00u_PCB
pgdn1: SW_Push; SW_Cherry_MX_1.00u_PCB
prtscrn1: SW_Push; SW_Cherry_MX_1.00u_PCB
scrlck1: SW_Push; SW_Cherry_MX_1.00u_PCB
voldown1: SW_Push; SW_Cherry_MX_1.00u_PCB
volup1: SW_Push; SW_Cherry_MX_1.00u_PCB

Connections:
/middle/VBAT3: BT3.1 (+), R5.1, U4.15 (BAT)
/middle/c0: U4.1 (P0.02_A0_D0), n2.1, n3.1, n4.1, n5.1, numlock1.1, prtscrn1.1
/middle/c1: .2.1, /1.1, U4.2 (P0.03_A1_D1), n6.1, n7.1, n8.1, scrlck1.1
/middle/c2: *1.1, U4.3 (P0.28_A2_D2), n9.1, n10.1, n11.1, pause1.1, volup1.1
/middle/c3: +1.1, U4.4 (P0.29_A3_D3), enter2.1, home1.1, instert1.1, n0\1.1, voldown1.1
/middle/c4: -2.1, U4.5 (P0.04_A4_D4_SDA), ctrlt1.1, ctrlw1.1, delete2.1, end1.1, pgdn1.1
/middle/pin: R5.2, R6.1, U4.17 (NFC1)
/middle/r0: D80.1 (K), D86.1 (K), D92.1 (K), D98.1 (K), D104.1 (K), U4.6 (P0.05_A5_D5_SCL)
/middle/r1: D81.1 (K), D87.1 (K), D93.1 (K), D99.1 (K), D105.1 (K), U4.7 (P1.11_D6_TX)
/middle/r2: D82.1 (K), D88.1 (K), D94.1 (K), D100.1 (K), D106.1 (K), U4.11 (P1.15_D10_MOSI)
/middle/r3: D83.1 (K), D89.1 (K), D95.1 (K), D101.1 (K), D107.1 (K), U4.10 (P1.14_D9_MISO)
/middle/r4: D84.1 (K), D90.1 (K), D96.1 (K), D102.1 (K), D108.1 (K), U4.9 (P1.13_D8_SCK)
/middle/r5: D85.1 (K), D91.1 (K), D97.1 (K), D103.1 (K), D109.1 (K), U4.8 (P1.12_D7_RX)
GND3: BT3.2 (-), R6.2, U4.13 (GND)
unnamed: D80.2 (A), prtscrn1.2
unnamed: D81.2 (A), numlock1.2
unnamed: D82.2 (A), n2.2
unnamed: D83.2 (A), n3.2
unnamed: D84.2 (A), n4.2
unnamed: D85.2 (A), n5.2
unnamed: D86.2 (A), scrlck1.2
unnamed: /1.2, D87.2 (A)
unnamed: D88.2 (A), n6.2
unnamed: D89.2 (A), n7.2
unnamed: D90.2 (A), n8.2
unnamed: .2.2, D91.2 (A)
unnamed: D92.2 (A), pause1.2
unnamed: *1.2, D93.2 (A)
unnamed: D94.2 (A), n9.2
unnamed: D95.2 (A), n10.2
unnamed: D96.2 (A), n11.2
unnamed: D97.2 (A), volup1.2
unnamed: D98.2 (A), instert1.2
unnamed: D99.2 (A), home1.2
unnamed: D100.2 (A), n0\1.2
unnamed: +1.2, D101.2 (A)
unnamed: D102.2 (A), enter2.2
unnamed: D103.2 (A), voldown1.2
unnamed: D104.2 (A), delete2.2
unnamed: D105.2 (A), end1.2
unnamed: D106.2 (A), pgdn1.2
unnamed: -2.2, D107.2 (A)
unnamed: D108.2 (A), ctrlw1.2
unnamed: D109.2 (A), ctrlt1.2

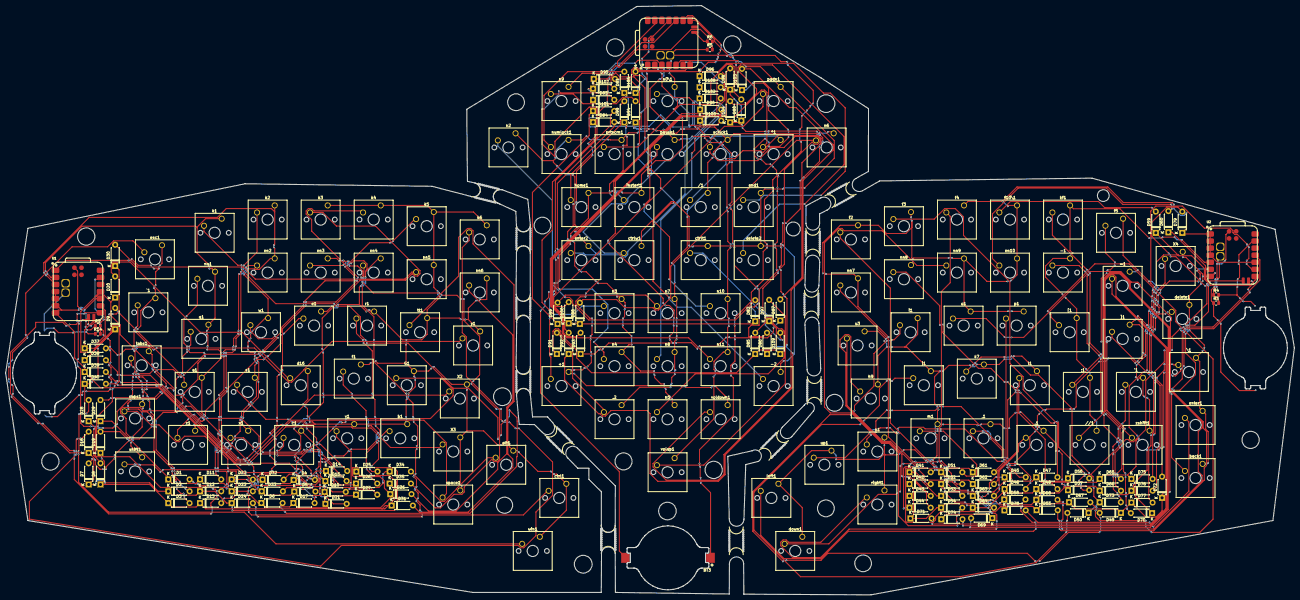
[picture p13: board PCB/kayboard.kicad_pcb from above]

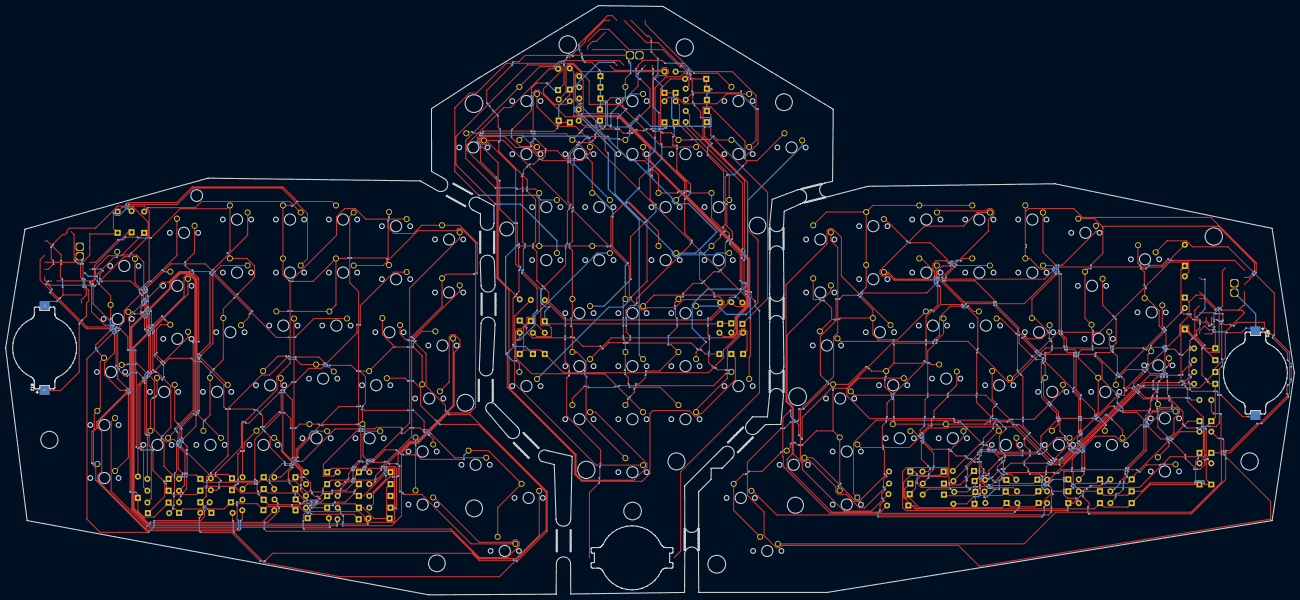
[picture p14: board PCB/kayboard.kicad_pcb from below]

Board: 2 copper layers, 463.0 x 211.7 mm, 240 parts (2 on the bottom side), 146 nets.
